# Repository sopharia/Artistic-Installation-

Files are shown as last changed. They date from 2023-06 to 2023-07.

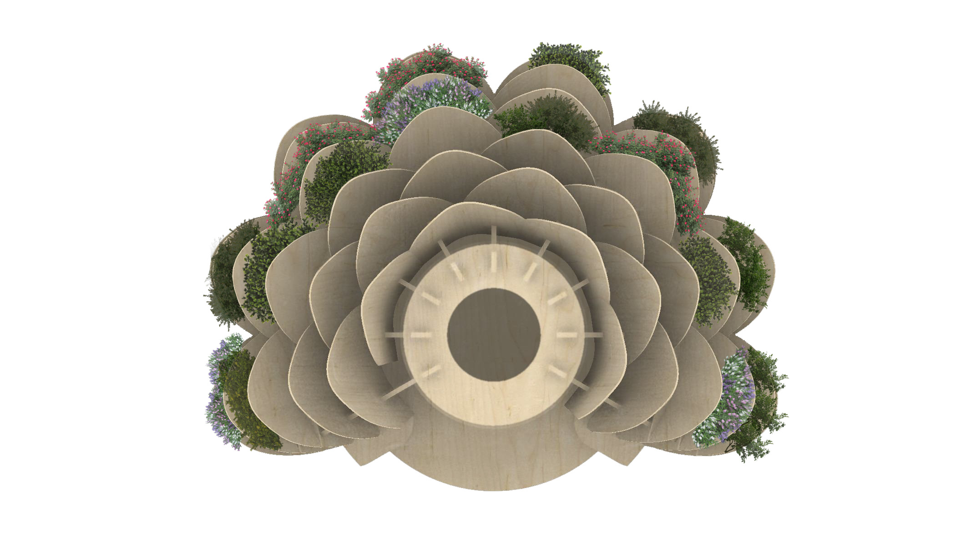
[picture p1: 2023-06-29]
ΡΕΝΤΕΡ ΚΑΤΟΨΗΣ .jpg

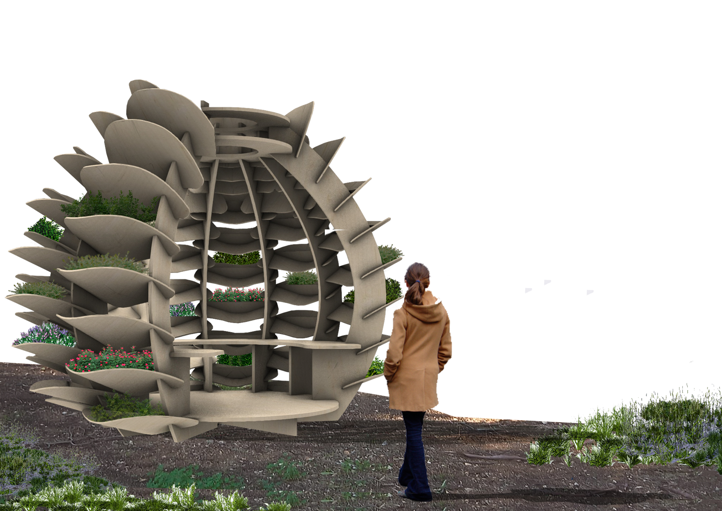
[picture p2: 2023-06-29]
ΦΩΤΟΡΕΑΛΙΣΤΙΚΟ.jpg

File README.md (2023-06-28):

# Artistic-Installation-
Our work is related to the design of a temporary art installation for the former Oasis camping site in Eleusina. As for the form of this installation, having as our goal from the beginning the design of constructions that would connect with the environment of the site and harmonize with the surrounding landscape, we started studying its natural and artificial elements. Through this study, and focusing on the natural environment, we noticed that there are various species of trees such as eucalyptus, palms and pines. The pines and especially the pine cone, caught our interest quite a bit and so we decided to experiment based on its shape. We started by accurately capturing its structure and studying it in all the phases it goes through until we reached its final form. We had in mind from the beginning that this particular art installation would ideally have a direct relationship with the natural environment and give the opportunity to young and old people to interact with it. For this reason, we decided that the structure would function as a small urban garden, where visitors would have the opportunity to plant and cultivate their own plants or herbs. The structure has an approximately circular shape on the perimeter of which there is a seat for rest and relaxation, while externally it is surrounded by leaves, small units of curved plywood wood, like the pine cone itself, which are also those that will host plants and various herbs. The construction consists of various pieces of plywood wood which are cut on a CNC machine and then assembled using angles and screws.

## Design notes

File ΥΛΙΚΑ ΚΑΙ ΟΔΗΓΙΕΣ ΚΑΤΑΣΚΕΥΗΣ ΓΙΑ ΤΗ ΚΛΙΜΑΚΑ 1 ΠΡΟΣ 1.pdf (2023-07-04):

### ΣΧΕΔΙΑ ΕΠΙΜΕΡΟΥΣ ΜΕΡΩΝ ΔΟΜΗΣ ΟΣΟΝ ΑΦΟΡΑ ΤΗ ΠΡΑΓΜΑΤΙΚΗ ΚΑΤΑΣΚΕΥΗ (ΚΛΙΜΑΚΑ 1/1)

ΠΑΝΕΠΙΣΤΗΜΙΟ ΘΕΣΣΑΛΙΑΣ Ι ΤΜΗΜΑ ΑΡΧΙΤΕΚΤΟΝΩΝ ΜΗΧΑΝΙΚΩΝ Ι ΑΚΑΔΗΜΑΙΚΟ ΕΤΟΣ 2022 - 2023

Τα συγκεκριμένα σχέδια αποτελούν τα επιμέρους μέρη της κατασκευής. Κόβονται σε CNC και πιο συγκεκριμένα είναι:
- 27 φύλλα κόντρα πλακέ θαλάσσης διαστάσεων 305x152,5cm
- 3 φύλλα κόντρα πλακέ θαλάσσης διαστάσεων 250x125cm
- 2 φύλλα κόντρα πλακέ θαλάσσης διαστάσεων 220x170cm

Τα συνδετικά μέρη της κατασκευής είναι:
- 148 ArteLibre μηχανόβιδες σταυρού γαλβανιζέ DIN 963 με διάμετρο M5 και μήκος 40mm
- 148 Spax ξυλόβιδες σταυρού μεταλλικές με διάμετρο M5 και μήκος 20mm
- 74 γωνιές σύνδεσης ξύλου 100 X 100 X 20MM

Εικ.32. Σχέδια επιμέρους κομματιών της δομής κλίμακα 1/1 (Πηγή: οι συγγραφείς)

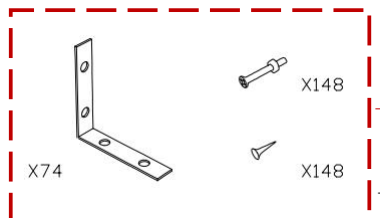
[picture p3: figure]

Εικ.33. Σχέδια των συνδετικών μερών της κατασκευής (Πηγή: οι συγγραφείς)

### ΓΕΝΙΚΕΣ ΠΛΗΡΟΦΟΡΙΕΣ ΓΙΑ ΤΙΣ ΣΥΝΔΕΣΕΙΣ ΤΩΝ ΜΕΡΩΝ ΤΗΣ ΚΑΤΑΣΚΕΥΗΣ

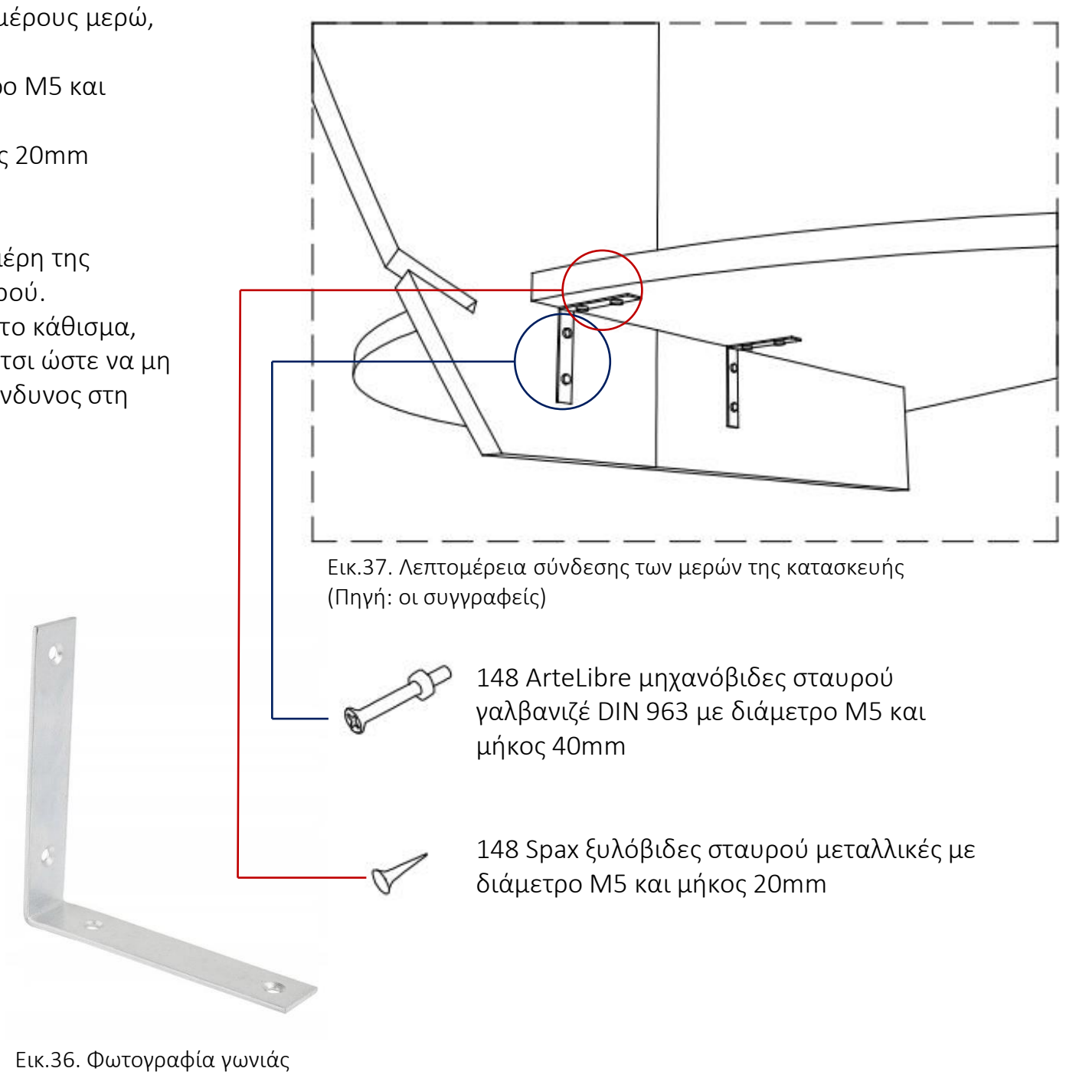
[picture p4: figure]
148 ArteLibre μηχανόβιδες σταυρού γαλβανιζέ DIN 963 με διάμετρο M5 και μήκος 40mm; διάμετρο M5 και μήκος 20mm; (Πηγή: οι συγγραφείς)

148 Spax ξυλόβιδες σταυρού μεταλλικές με

Όσον αφορά το κατασκευαστικό κομμάτι, για την σύνδεση των επιμέρους μερώ, χρησιμοποιούνται γωνιές 100x100x20mm και δυο ειδών βίδες:
- ArteLibre μηχανόβιδες σταυρού γαλβανιζέ DIN 963 με διάμετρο M5 και μήκος 40mm
- Spax ξυλόβιδες σταυρού μεταλλικές με διάμετρο M5 και μήκος 20mm

Πιο συγκεκριμένα, για την κατασκευή:
- Στην επιφάνεια της γωνιάς που εφάπτεται με τα κατακόρυφα μέρη της κατασκευής, χρησιμοποιούνται οι ArteLibre μηχανόβιδες σταυρού.
- Στην επιφάνεια των γωνιών που εφάπτονται με το πάτωμα και το κάθισμα, χρησιμοποιούνται οι Spax ξυλόβιδες σταυρού μήκους 20mm έτσι ώστε να μη διαπερνούν το πάχος του ξύλου των επιφανειών και υπάρξει κίνδυνος στη χρήση της κατασκευής.

Εικ.37. Λεπτομέρεια σύνδεσης των μερών της κατασκευής

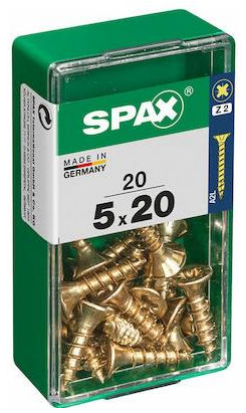
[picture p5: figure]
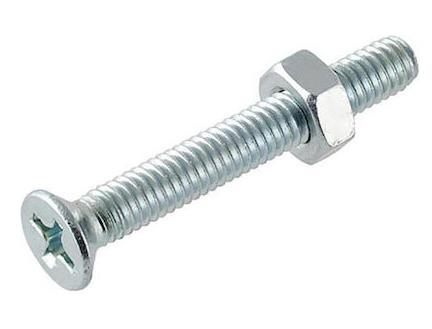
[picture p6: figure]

Εικ.34. Φωτογραφία | Εικ.36. Φωτογραφία γωνιάς
μηχανόβιδας σταυρού

Εικ.35. Φωτογραφία
ξυλόβιδων σταυρού

### ΟΔΗΓΙΕΣ ΚΑΤΑΣΚΕΥΗΣ ΤΗΣ ΔΟΜΗΣ ΟΣΟΝ ΑΦΟΡΑ ΤΗ ΚΛΙΜΑΚΑ 1/1

ΒΗΜΑ 1 | ΒΗΜΑ 2 | ΒΗΜΑ 3 | ΒΗΜΑ 4 | ΒΗΜΑ 5

ΒΙΔΑ ΣΥΝΔΕΣΗΣ ΚΑΤΑΚΟΡΥΦΩΝ ΜΕΡΩΝ

ΒΙΔΑ ΣΥΝΔΕΣΗΣ ΠΑΤΩΜΑΤΟΣ ΚΑΙ ΚΑΘΙΣΜΑΤΟΣ

- ΒΗΜΑ 1: Σύνδεση των δυο μερών της κατασκευής με ειδική ξυλόκολλα
- ΒΗΜΑ 2: Σύνδεση του πρώτου κατακόρυφου μέρους της κατασκευής με την επιφάνεια του πατώματος με γωνιές και Spax ξυλόβιδες σταυρού και ArteLibre μηχανόβιδες σταυρού
- ΒΗΜΑ 3: Τοποθέτηση του δεύτερου κατακόρυφου μέρους με το πάτωμα με τις παραπάνω βίδες
- ΒΗΜΑ 4 και 5: Τοποθέτηση των υπόλοιπων κατακόρυφων μερών με τις ίδιες βίδες.

Εικ.38. Σχέδια οδηγιών κατασκευής της δομής στην κλίμακα 1/1 (Πηγή: οι συγγραφείς)

Εικ.39. Λεπτομέρεια 1 τρόπου σύνδεσης του πατώματος με τα κατακόρυφα στοιχεία μερών
(Πηγή: οι συγγραφείς)

Εικ.40. Λεπτομέρεια 2 τρόπου σύνδεσης του καθιστικού με τα κατακόρυφα στοιχεία (Πηγή: οι συγγραφείς)

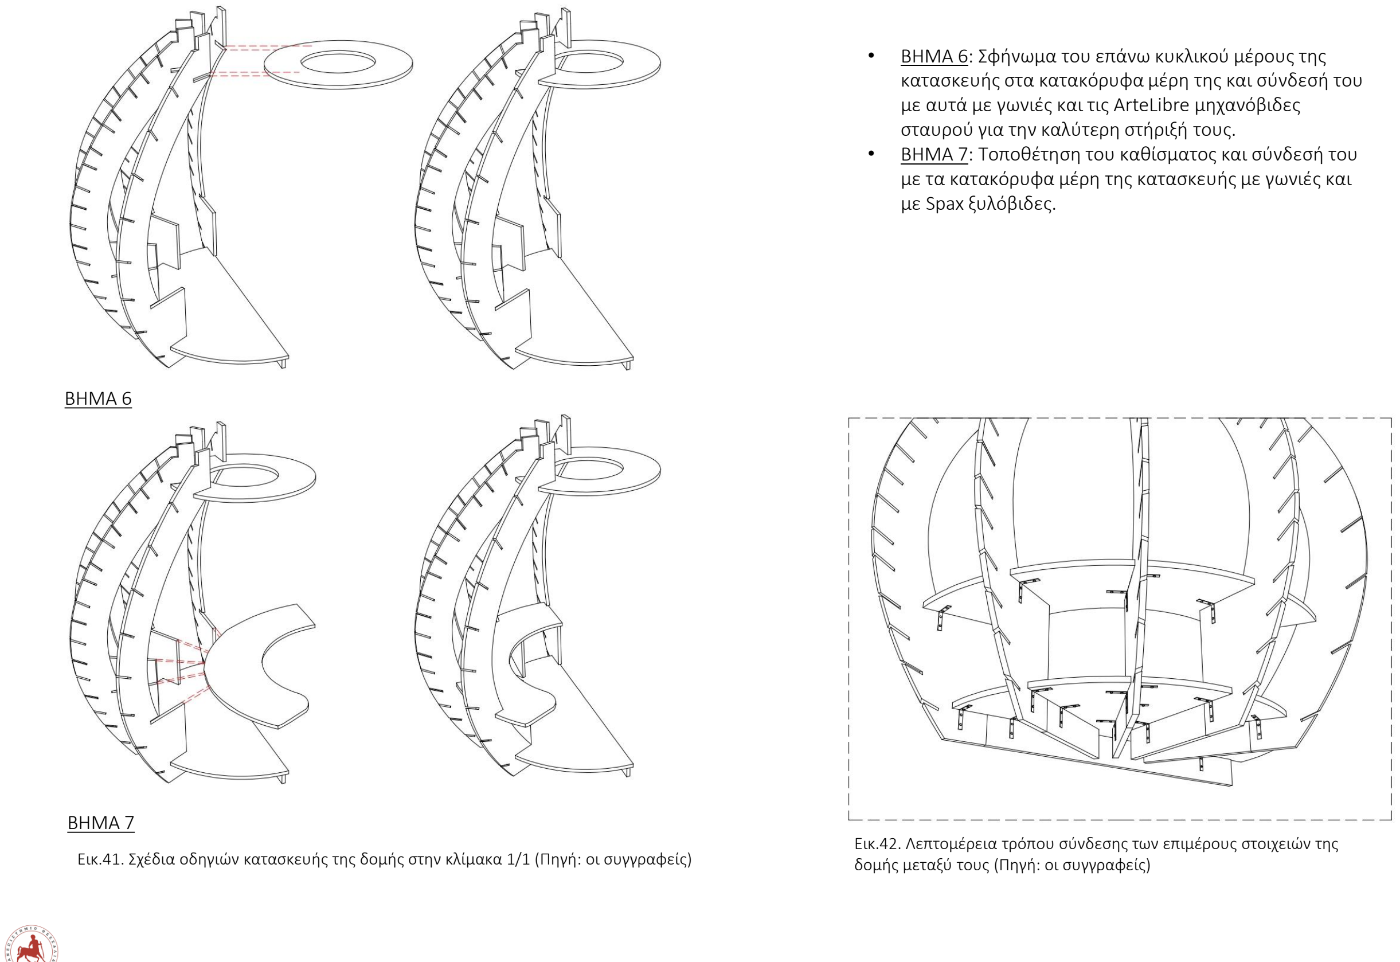
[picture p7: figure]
ΒΗΜΑ 6; ΒΗΜΑ 7; σταυρού για την καλύτερη στήριξή τους.; με Spax ξυλόβιδες.; δομής μεταξύ τους (Πηγή: οι συγγραφείς)

- ΒΗΜΑ 6: Σφήνωμα του επάνω κυκλικού μέρους της κατασκευής στα κατακόρυφα μέρη της και σύνδεσή του με αυτά με γωνιές και τις ArteLibre μηχανόβιδες
- ΒΗΜΑ 7: Τοποθέτηση του καθίσματος και σύνδεσή του με τα κατακόρυφα μέρη της κατασκευής με γωνιές και

Εικ.41. Σχέδια οδηγιών κατασκευής της δομής στην κλίμακα 1/1 (Πηγή: οι συγγραφείς)

Εικ.42. Λεπτομέρεια τρόπου σύνδεσης των επιμέρους στοιχειών της

- ΒΗΜΑ 8: Κατασκευή της άλλης μισής δομής με τον ίδιο τρόπο, δηλαδή σύνδεση των δυο πρώτων κατακόρυφων μερών με την επιφάνεια του πατώματος και το κάθισμα με χρήση γωνιών και των δυο διαφορετικών βιδών που προαναφέρθηκαν.
- ΒΗΜΑ 9: Τοποθέτηση και των δυο τελευταίων κατακόρυφων μερών στην κατασκευή με γωνιές και με βίδες

ΒΗΜΑ 8

ΒΗΜΑ 9

Εικ.43. Σχέδια οδηγιών κατασκευής της δομής στην κλίμακα 1/1 (Πηγή: οι συγγραφείς)

Εικ.44. Λεπτομέρεια τρόπου σύνδεσης των επιμέρους στοιχειών της δομής μεταξύ τους (Πηγή: οι συγγραφείς)

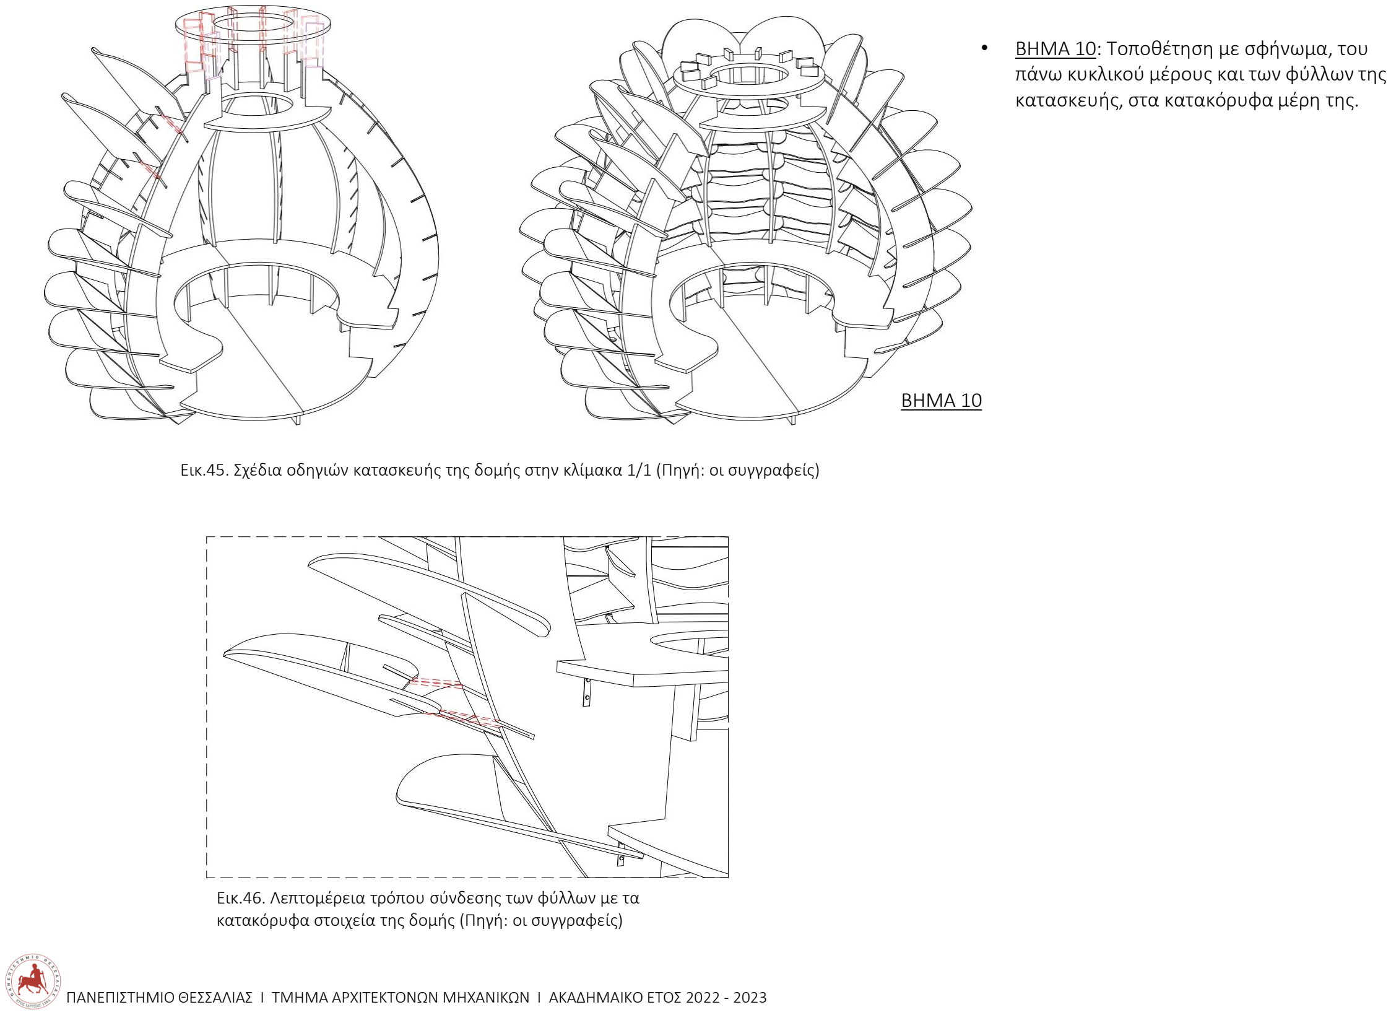
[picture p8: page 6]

Εικ.46. Λεπτομέρεια τρόπου σύνδεσης των φύλλων με τα κατακόρυφα στοιχεία της δομής (Πηγή: οι συγγραφείς)

- ΒΗΜΑ 10: Τοποθέτηση με σφήνωμα, του πάνω κυκλικού μέρους και των φύλλων της κατασκευής, στα κατακόρυφα μέρη της.

ΒΗΜΑ 10

Εικ.45. Σχέδια οδηγιών κατασκευής της δομής στην κλίμακα 1/1 (Πηγή: οι συγγραφείς)

### ΔΙΑΔΙΚΑΣΙΑ ΚΑΜΠΥΛΩΣΗΣ ΤΟΥ ΦΥΛΟΥ ΟΣΟ ΑΦΟΡΑ ΤΗΝ ΠΡΑΓΜΑΤΙΚΗ ΚΑΤΑΣΚΕΥΗ (ΚΛΙΜΑΚA 1/1)

Η διαδικασία που ακολουθείται για την καμπύλωση του κόντρα πλακέ ξύλου είναι η εξής:
- Κόβεται το σχήμα του φύλου σε ξύλο κόντρα πλακέ μέσω CNC μηχανών.
- Το ξύλο ατμίζεται σε θερμοκρασία 80 εως 140C .
- Στη συνέχεια υφίσταται συμπίεση παράλληλα προς τις ίνες σε ειδική πρέσα.
- Κατά τη διαδικασία συμπίεσης οι ίνες του ξύλου κάμπτονται και το ξύλο καμπυλώνει χωρίς να παραμορφώνεται.

Αφού καμπυλωθεί το κόντρα πλακέ του φύλου, σφηνώνεται σε αυτό το στοπ που έχει κοπεί σε μηχάνημα CNC, όπως φαίνεται στο τελευταίο σχέδιο.

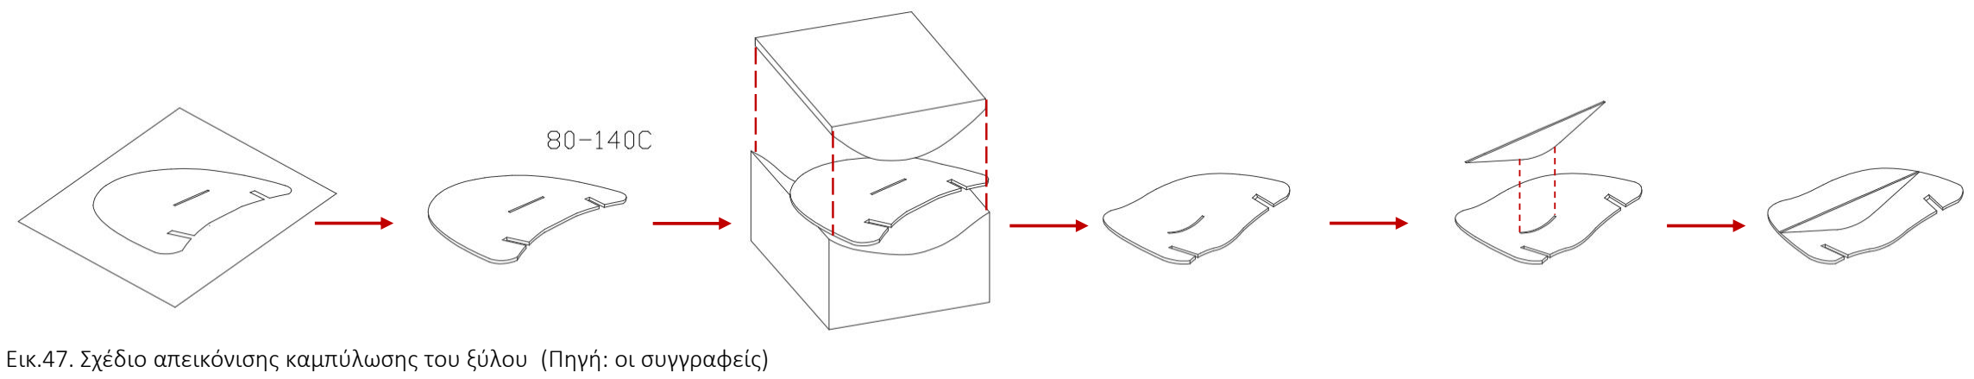
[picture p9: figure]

Εικ.47. Σχέδιο απεικόνισης καμπύλωσης του ξύλου (Πηγή: οι συγγραφείς)

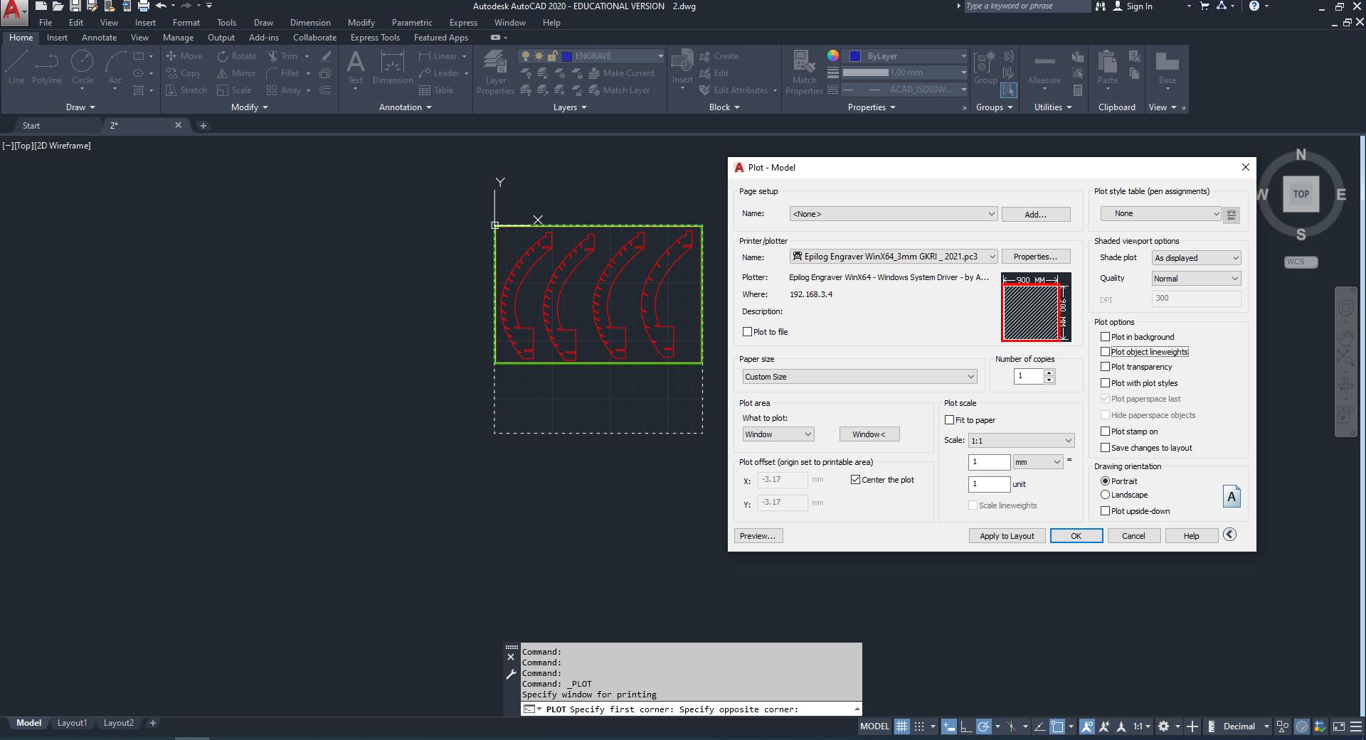
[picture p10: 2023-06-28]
ΡΥΘΜΙΣΕΙΣ ΓΙΑ ΤΗ ΚΟΠΗ ΣΕ LASER ΓΙΑ ΜΑΚΕΤΑ.JPG

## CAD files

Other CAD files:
ΜΕΡΗ ΚΑΤΑΣΚΕΥΗΣ.dwg
ΚΟΠΗ ΣΕ CNC ΓΙΑ ΤΗ ΚΛΙΜΑΚΑ 1 ΠΡΟΣ 1.dwg
ΣΧΕΔΙΑ .dwg
